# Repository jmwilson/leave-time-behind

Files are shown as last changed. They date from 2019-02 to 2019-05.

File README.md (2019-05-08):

## Introduction

*Leave Time Behind* is experimental timepiece that invites the viewer to have a looser hold on time. The project takes the form of a desk clock that displays time as a continuous glowing bar that advances gradually over the course of the day. Compared to a traditional clock that allows us to obsess over hours and minutes, *Leave Time Behind* only permits the viewer to mark time and intervals approximately in relation to the natural cycle of the day.

The project was inspired by my experiences at Camp Grounded, a tech-free summer camp for adults. One of the rules of camp was to "leave time behind" -- for a weekend, we put away watches, phones, and alarms, and measured time only by the sun and stars.

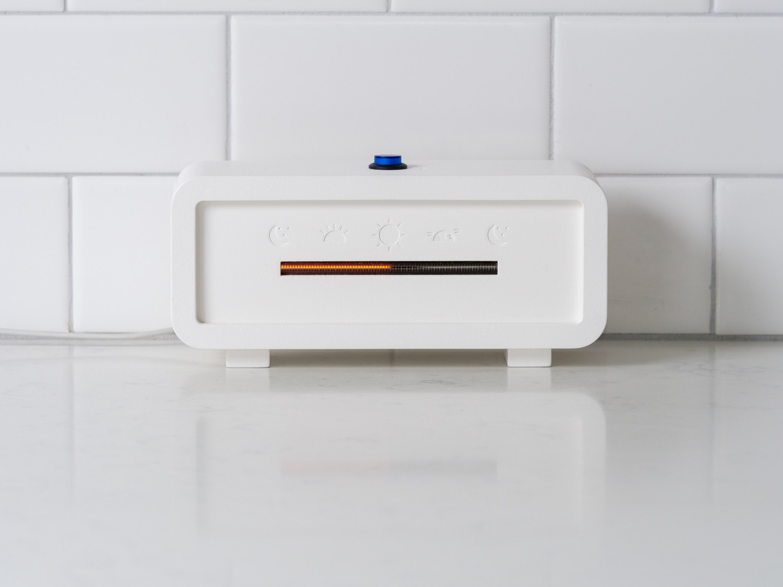
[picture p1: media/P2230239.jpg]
Picture of clock


## Details

The desk clock is primarily an electronic device. A custom printed circuit board (PCB) houses the main components of the electronics design: a switched-mode DC-DC power supply, a microcontroller with Bluetooth low-energy connectivity that keeps time, and a driver circuit that converts the digital time output from the microcontroller to an analog control signal.

The time is displayed on an IN-13 [Nixie tube](https://en.wikipedia.org/wiki/Nixie_tube). By varying the current through the tube, the length of the glowing segment can be controlled. Nixie tubes were chosen for their warm glow and analog aethestic.

When I thought of the design of the clock, I wanted it to have the minimum interface possible. In keeping with the aim to de-emphasize attention to hours and minutes, there are no discrete controls to set the exact time. To set the time, a single button on the top of the enclosure activates the Bluetooth function. When paired with a smartphone, the clock reads the time from the device.

I wanted the clock to work without the need for special wall adapters or connectors, and considered the USB phone charger to be the ideal power adapter that everyone has that could be reused or repurposed. Since USB provides power at 5 VDC, whereas Nixie tubes have a typical firing voltage of 150 - 170 VDC, this required a custom switched-mode DC-DC power supply. The power supply operates in [boost topology](https://en.wikipedia.org/wiki/Boost_converter) in discontinuous current mode (DCM) at a switching frequency of 100 kHz.

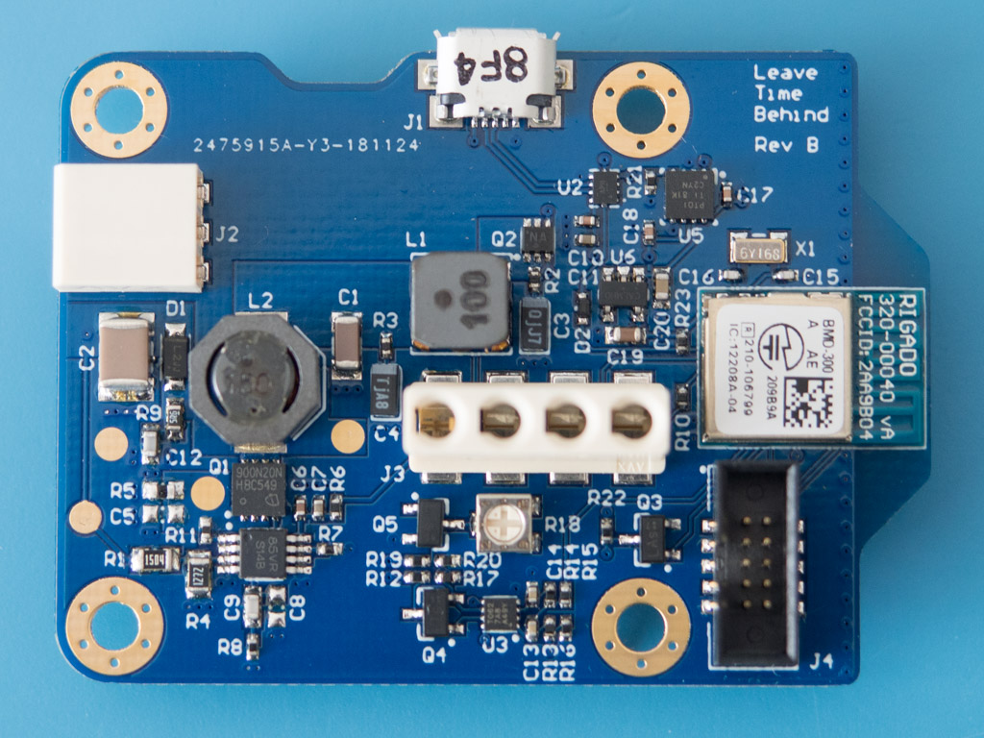
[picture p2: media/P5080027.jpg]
Closeup of PCB

*Close-up of the PCB*

## Future work

The clock enclosure was 3D printed from nylon plastic for expediency, but my original concept called for a wood enclosure that would complement the warm, retro aesthetic of the Nixie tube.

An alternative to bootstrapping the time from a smartphone is to use GPS to determine the time relative to local sunrise and sunset. Such a clock could set its own time without any interaction. Since it would display time relative to sunrise and sunset, it need not be concerned with the vagaries of time zones or daylight saving time.

## Understanding this repository

`CAD files`: details of the physical enclosure design including STL files that can be 3D-printed. The enclosure was designed using [Autodesk Fusion 360](https://www.autodesk.com/products/fusion-360/overview).

`PCB`: design files for the printed circuit board, including schematic sheets and layouts. The circuit board was designed using [Altium Designer](https://www.altium.com/altium-designer/). The latest Gerber files for manufacturing are in `Gerbers.zip`. A PDF of the compiled schematic sheets is in `Schematic.pdf`.

`Design scripts` and `spice`: contains various simulation and scripts primarily for the design and tuning of the switching power supply. The simulations use [LTspice](https://www.linear.com/ltspice), a free-to-use SPICE implementation.

`Scope captures`: oscilloscope screen captures documenting the performance and characteristics of the power supply. Most of the captures are annotated with the subject and conditions of the test.

`firmware`: C code for the [nRF5 microcontroller](https://www.nordicsemi.com/).

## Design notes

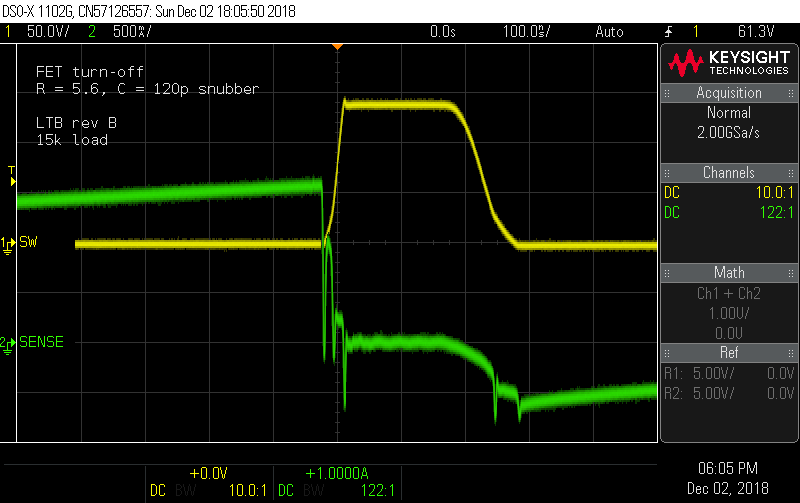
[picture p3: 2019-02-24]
Scope captures/Rev B/scope_15.png

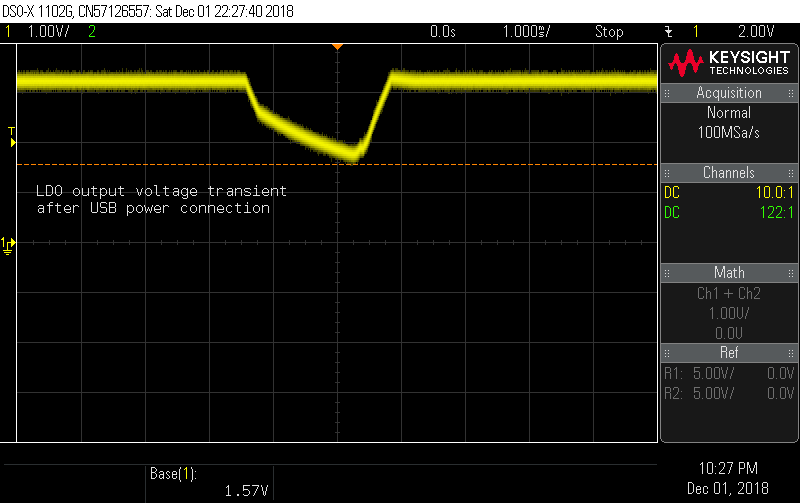
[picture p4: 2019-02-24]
Scope captures/Rev B/scope_12.png

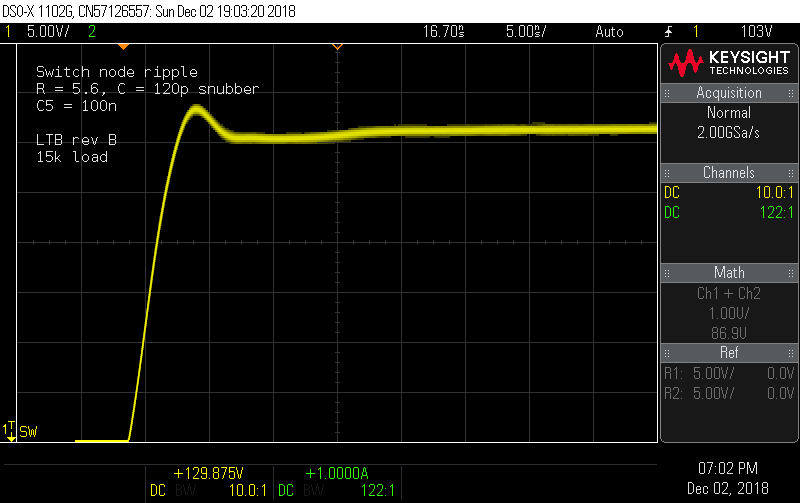
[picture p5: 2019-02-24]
Scope captures/Rev B/scope_22.png

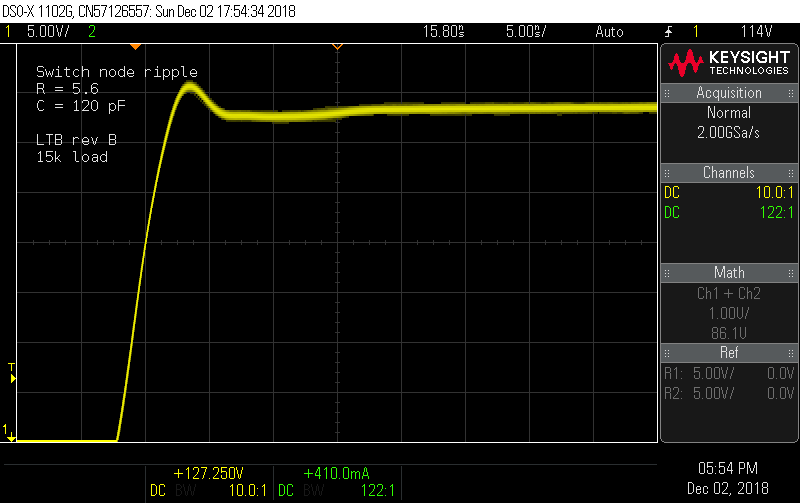
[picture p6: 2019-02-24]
Scope captures/Rev B/scope_14.png

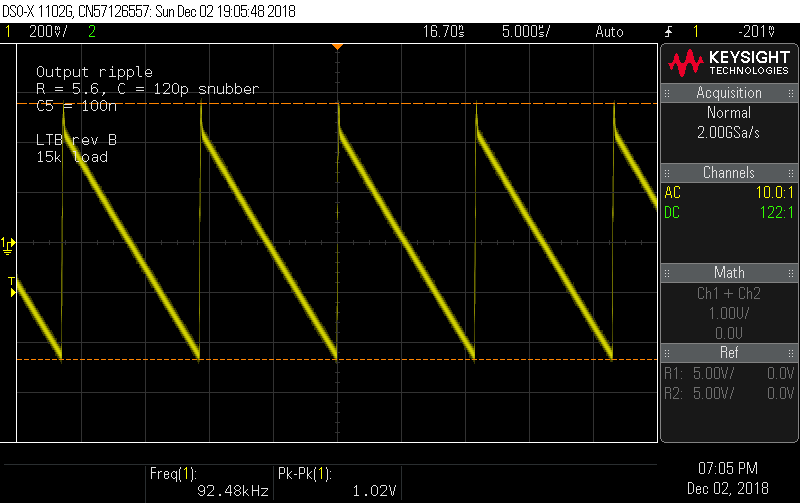
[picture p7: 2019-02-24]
Scope captures/Rev B/scope_23.png

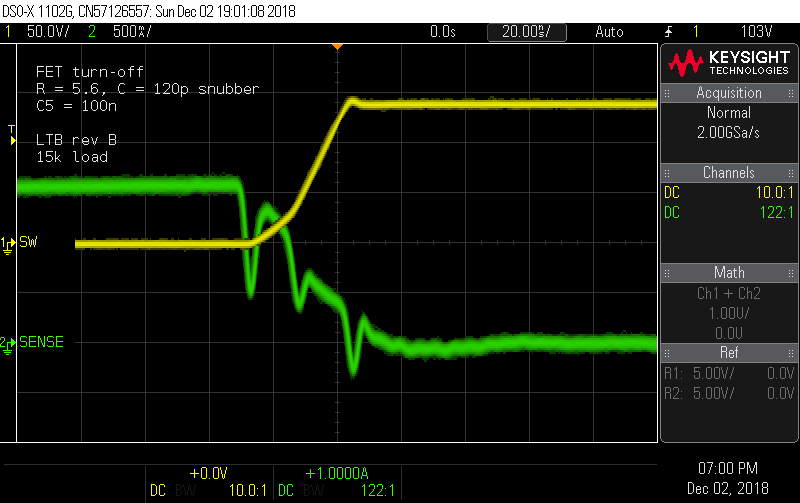
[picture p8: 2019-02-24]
Scope captures/Rev B/scope_21.png

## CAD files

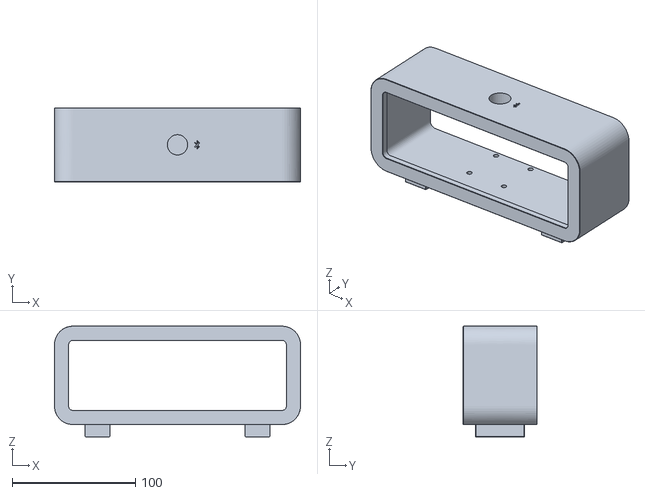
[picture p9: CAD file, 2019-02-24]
CAD files/Frame.stl
200.0 x 60.0 x 90.0

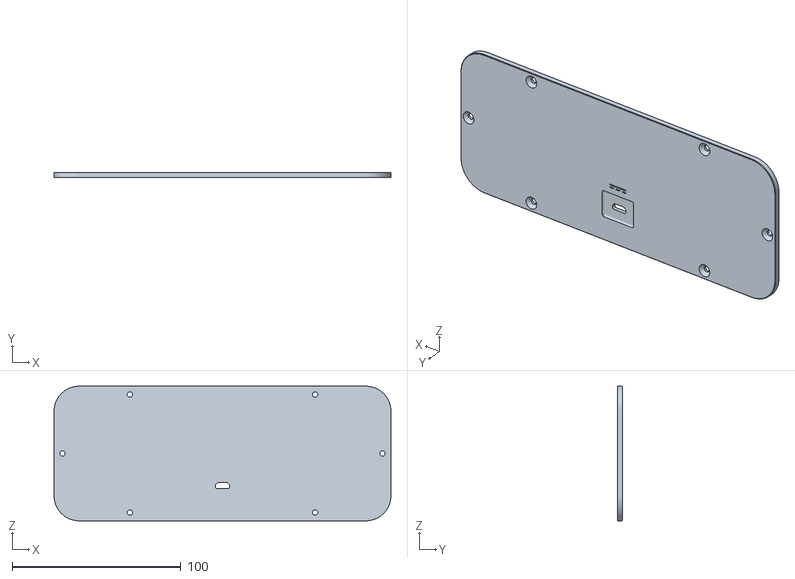
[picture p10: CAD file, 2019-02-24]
CAD files/Back panel.stl
200.0 x 3.00 x 80.0

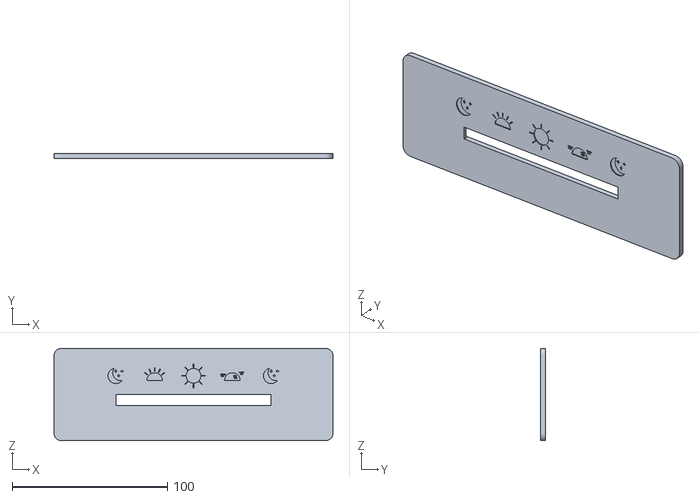
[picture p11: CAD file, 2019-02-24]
CAD files/Front panel.stl
179.5 x 3.00 x 59.5

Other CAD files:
CAD files/Enclosure.f3z

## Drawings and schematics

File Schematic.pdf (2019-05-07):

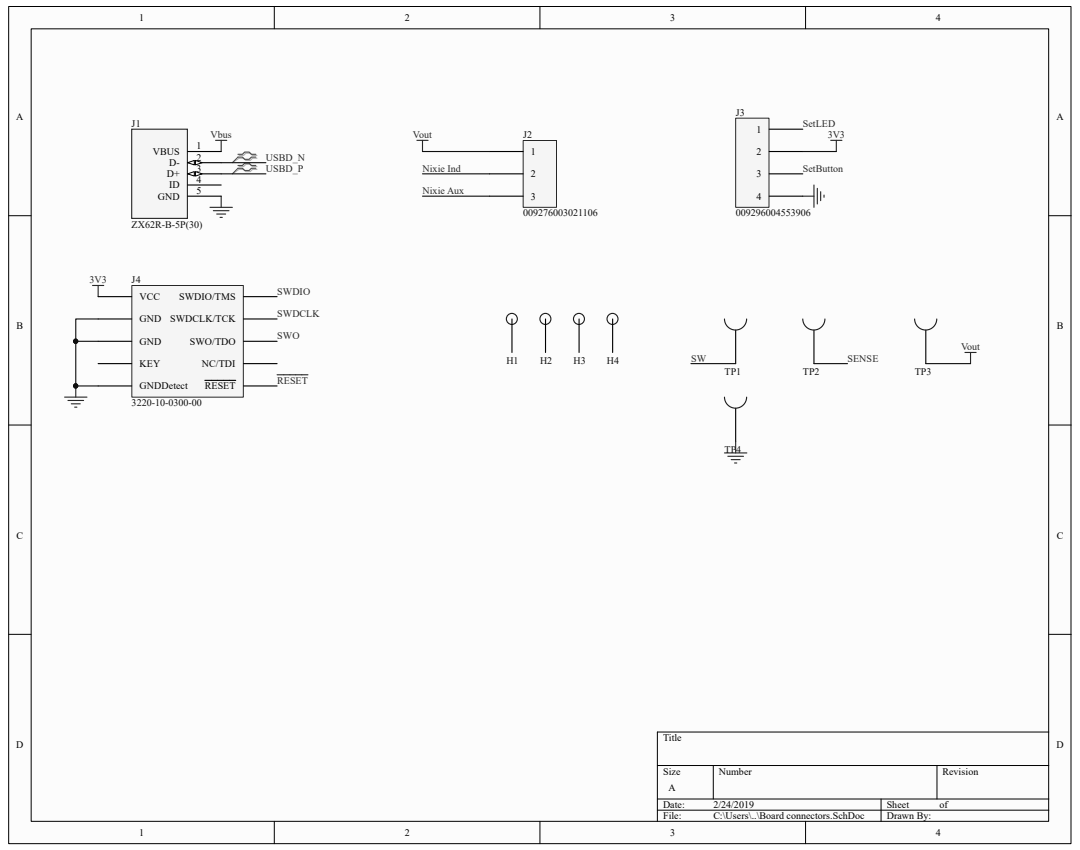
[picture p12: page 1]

IN1+ 4 8

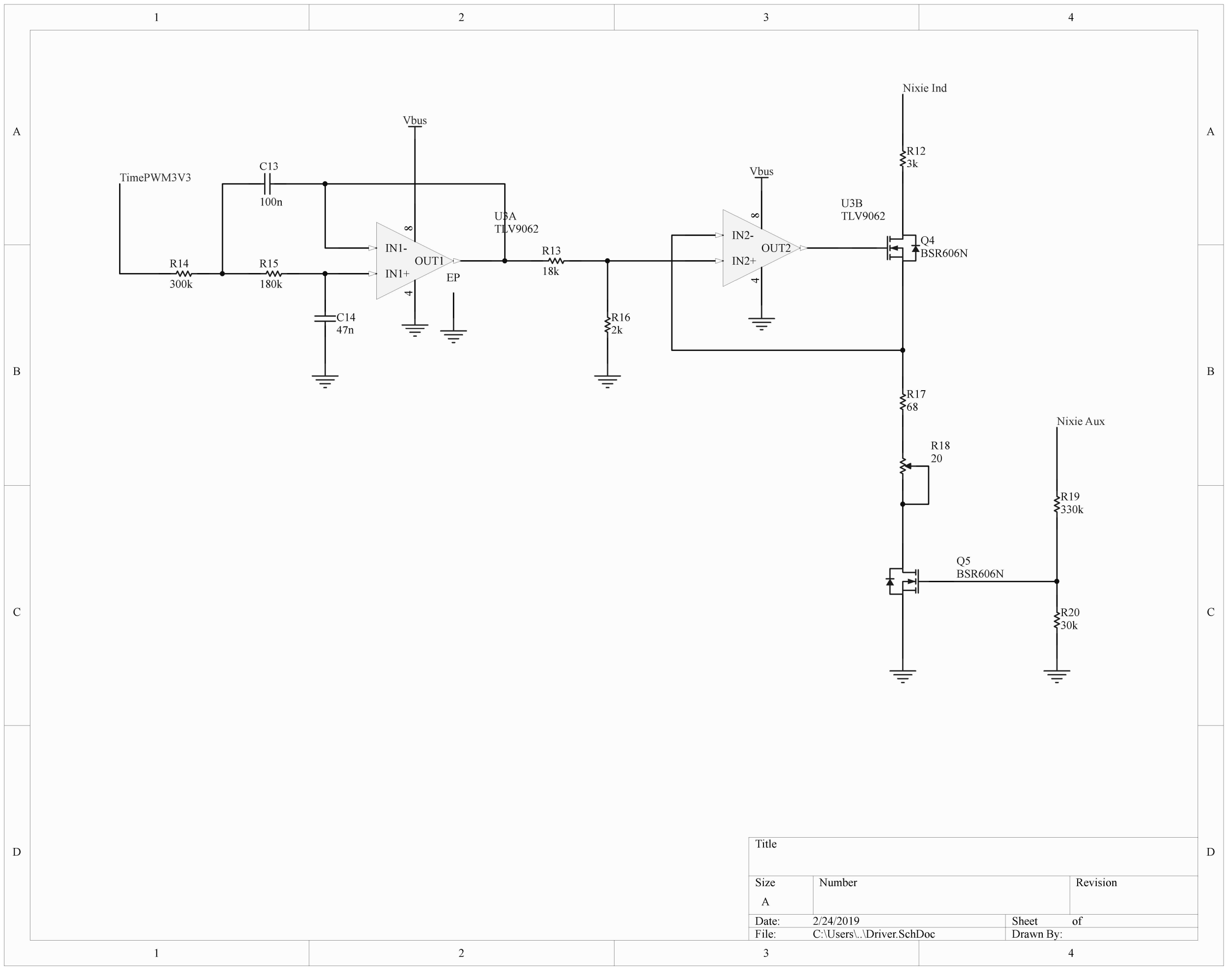
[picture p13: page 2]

D D

C C

B B

A A

Title

Size | Number | Revision
File: | C:\Users\..\Driver.SchDoc | Drawn By:

EP

OUT1

IN1-

U3A
TLV9062 | 4 8 OUT2
| IN2-
| IN2+

U3B
TLV9062

Vbus

Vbus TimePWM3V3

R14
300k

R15
180k

C13

100n

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
330k

R20
30k

R18
20

Q4
BSR606N

Q5
BSR606N

Nixie Ind

Nixie Aux

# U4 SetButton

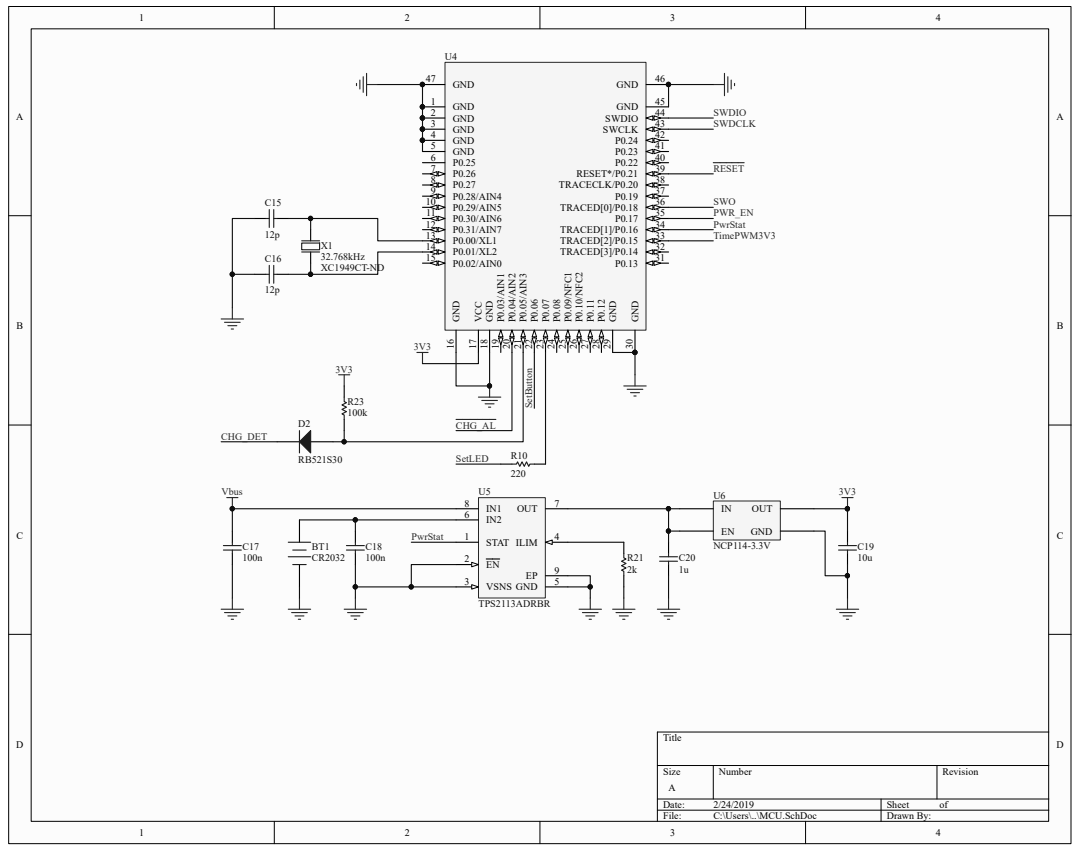
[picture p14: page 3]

4 5, 6, 7, 8, 9 1, 2, 3

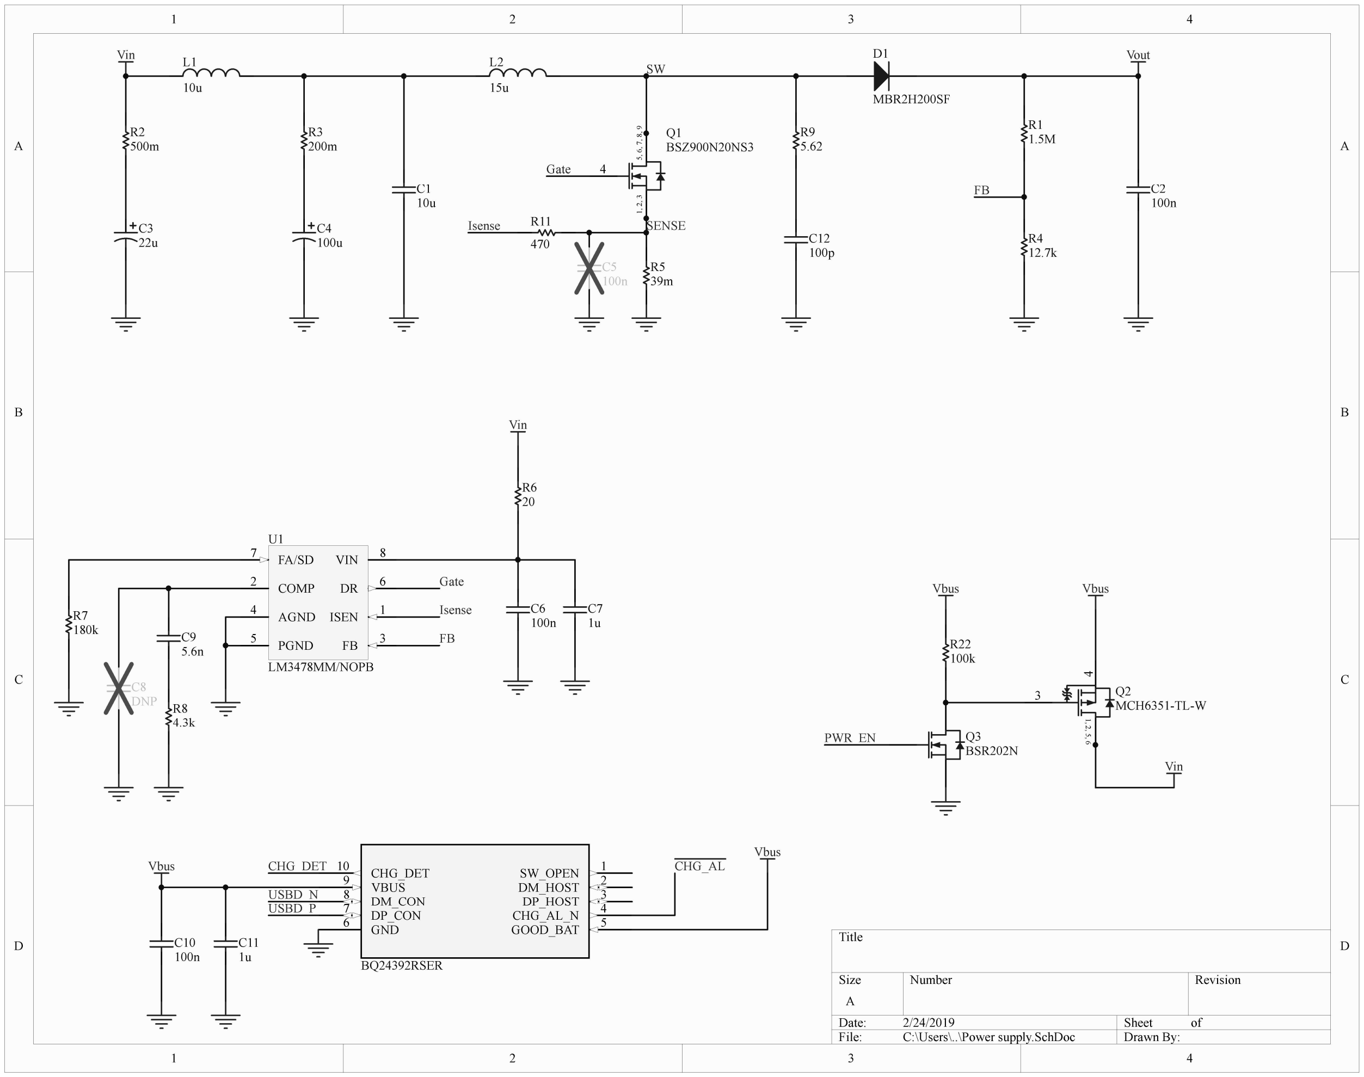
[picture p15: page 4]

D D

C C

B B

A A

Title

Size | Number | Revision
File: | C:\Users\..\Power supply.SchDoc | Drawn By:
VIN | 8
DR | 6

PGND 5

AGND 4

ISEN 1

FA/SD 7

COMP 2

FB 3

U1

LM3478MM/NOPB

SW_OPEN | 1
DM_HOST | 2
DP_HOST | 3
CHG_AL_N | 4
GOOD_BAT | 5 GND 6

DP_CON 7

DM_CON 8

VBUS 9

CHG_DET 10

BQ24392RSER

CHG_DET

Vbus

Isense

Isense

D1

MBR2H200SF

R1
1.5M

R4
12.7k

FB

FB

Vout

R6
20

Gate

Gate
C1
10u

C6
100n

USBD_N
USBD_P

Vbus

C10
100n

3 4 1, 2, 5, 6
Q2
MCH6351-TL-W

Vbus

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
100u

C8
DNP

R2
500m

R3
200m

C7
1u

C11
1u

PWR_EN

SW

SENSE

C5
100n

CHG_AL

Q1
BSZ900N20NS3

L2

15u

Q3
BSR202N

Vbus

R22
100k

C2
100n

R9
5.62

C12
100p

R7
180k | C9
| 5.6n

R8
4.3k

R5
39m

R11
470

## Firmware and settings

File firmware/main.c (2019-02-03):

/**
 * Copyright (c) 2018-2019 James Wilson
 * All rights reserved.
 *
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
 * You should have received a copy of the GNU General Public License
 * along with this program.  If not, see <https://www.gnu.org/licenses/>.
 */

#include <stdint.h>
#include <string.h>
#include "nrf.h"
#include "app_error.h"
#include "app_scheduler.h"
#include "app_timer.h"
#include "ble.h"
#include "ble_cts_c.h"
#include "ble_db_discovery.h"
#include "ble_hci.h"
#include "ble_srv_common.h"
#include "ble_advdata.h"
#include "ble_advertising.h"
#include "ble_conn_params.h"
#include "bsp.h"
#include "peer_manager.h"
#include "nordic_common.h"
#include "nrf_sdh.h"
#include "nrf_sdh_soc.h"
#include "nrf_sdh_ble.h"
#include "nrfx_gpiote.h"
#include "nrfx_pwm.h"
#include "ble_conn_state.h"
#include "nrf_ble_gatt.h"
#include "nrf_ble_qwr.h"

#include "nrf_log.h"
#include "nrf_log_ctrl.h"
#include "nrf_log_default_backends.h"

#include "nrf_calendar.h"


#define DEVICE_NAME                     "Leave Time Behind"

#define APP_BLE_OBSERVER_PRIO           3
#define APP_BLE_CONN_CFG_TAG            1  // A tag identifying the SoftDevice BLE configuration

#define APP_ADV_FAST_INTERVAL           0x0028  // Fast advertising interval (in units of 0.625 ms) = 25 ms
#define APP_ADV_SLOW_INTERVAL           0x0C80  // Slow advertising interval (in units of 0.625 ms) = 2s

#define APP_ADV_FAST_DURATION           3000   // Fast Advertising duration in units of 10 milliseconds
#define APP_ADV_SLOW_DURATION           18000  // Slow advertising duration in units 10 milliseconds


#define MIN_CONN_INTERVAL               MSEC_TO_UNITS(500, UNIT_1_25_MS)   // Minimum acceptable connection interval (0.5 seconds)
#define MAX_CONN_INTERVAL               MSEC_TO_UNITS(1000, UNIT_1_25_MS)  // Maximum acceptable connection interval (1 second)
#define SLAVE_LATENCY                   0
#define CONN_SUP_TIMEOUT                MSEC_TO_UNITS(4000, UNIT_10_MS)  // Connection supervisory time-out (4 seconds)
#define FIRST_CONN_PARAMS_UPDATE_DELAY  APP_TIMER_TICKS(5000)  // Time from connect to first sd_ble_gap_conn_param_update
#define NEXT_CONN_PARAMS_UPDATE_DELAY   APP_TIMER_TICKS(30000)  // Time between subsequent calls to sd_ble_gap_conn_param_update
#define MAX_CONN_PARAMS_UPDATE_COUNT    3  // Number of attempts before giving up the connection parameter negotiation

// Parameters for Just Works security and no IO capabiltiies
#define SEC_PARAM_BOND                  0
#define SEC_PARAM_MITM                  0
#define SEC_PARAM_LESC                  0
#define SEC_PARAM_KEYPRESS              0
#define SEC_PARAM_IO_CAPABILITIES       BLE_GAP_IO_CAPS_NONE
#define SEC_PARAM_OOB                   0
#define SEC_PARAM_MIN_KEY_SIZE          7
#define SEC_PARAM_MAX_KEY_SIZE          16

#define SCHED_MAX_EVENT_DATA_SIZE       APP_TIMER_SCHED_EVENT_DATA_SIZE
#ifdef SVCALL_AS_NORMAL_FUNCTION
// Maximum number of events in the scheduler queue.
#define SCHED_QUEUE_SIZE                20
#else
#define SCHED_QUEUE_SIZE                10
#endif

#define DEAD_BEEF                       0xDEADBEEF


BLE_CTS_C_DEF(m_cts_c);  // Current Time service instance
NRF_BLE_GATT_DEF(m_gatt);  // GATT module instance
NRF_BLE_QWR_DEF(m_qwr);  // Context for the Queued Write module
BLE_ADVERTISING_DEF(m_advertising);  // Advertising module instance
BLE_DB_DISCOVERY_DEF(m_ble_db_discovery);  // DB discovery module instance

static bool         m_pwr_en = false;  // Power state, true = on USB power, false = on backup battery
static uint16_t     m_cur_conn_handle = BLE_CONN_HANDLE_INVALID;  // Handle of the current connection

#define PWM_INVERT_OUTPUT ((uint16_t)0x8000)
#define PWM_TOP_VALUE 1600  // At 16 MHz, this sets a PWM frequency of 10 kHz
#define PWM_BASE_VALUE 160  // Beginning of the working section is about 10% of the max current
static nrfx_pwm_t pwm_inst = NRFX_PWM_INSTANCE(0);
static nrf_pwm_values_common_t pwm_values[] = {PWM_INVERT_OUTPUT | 0};

static ble_uuid_t m_adv_uuids[] = {{BLE_UUID_CURRENT_TIME_SERVICE, BLE_UUID_TYPE_BLE}};

APP_TIMER_DEF(ble_disconnect_timer);


/**
 * Callback function for asserts in the SoftDevice.
 *
 * @param[in] line_num  Line number of the failing ASSERT call.
 * @param[in] file_name File name of the failing ASSERT call.
 */
void assert_nrf_callback(uint16_t line_num, const uint8_t * p_file_name)
{
    app_error_handler(DEAD_BEEF, line_num, p_file_name);
}


static void advertising_start(void)
{
    ret_code_t ret;

    ret = ble_advertising_start(&m_advertising, BLE_ADV_MODE_FAST);
    if (ret != NRF_ERROR_INVALID_STATE) {
        APP_ERROR_CHECK(ret);
    }
}


static void pm_evt_handler(pm_evt_t const * p_evt)
{
    ret_code_t err_code;

    switch (p_evt->evt_id) {
        case PM_EVT_CONN_SEC_SUCCEEDED:
            NRF_LOG_INFO("Connection secured: role: %d, conn_handle: 0x%x, procedure: %d.",
                         ble_conn_state_role(p_evt->conn_handle),
                         p_evt->conn_handle,
                         p_evt->params.conn_sec_succeeded.procedure);

            // Discover peer's services.
            err_code  = ble_db_discovery_start(&m_ble_db_discovery, p_evt->conn_handle);
            APP_ERROR_CHECK(err_code);
            break;

        case PM_EVT_CONN_SEC_FAILED:
            break;

        case PM_EVT_ERROR_UNEXPECTED:
            APP_ERROR_CHECK(p_evt->params.error_unexpected.error);
            break;

        default:
            break;
    }
}


/**
 * Handler for Current Time Service errors.
 *
 * @param[in]  nrf_error  Error code containing information about what went wrong.
 */
static void current_time_error_handler(uint32_t nrf_error)
{
    APP_ERROR_HANDLER(nrf_error);
}


static void ble_disconnect_timer_handler(void *p_context)
{
    ble_cts_c_t *cts = (ble_cts_c_t *)p_context;
    (void)sd_ble_gap_disconnect(cts->conn_handle,
                                BLE_HCI_REMOTE_USER_TERMINATED_CONNECTION);
}


static void timers_init(void)
{
    ret_code_t err_code;

    err_code = app_timer_init();
    APP_ERROR_CHECK(err_code);

    err_code = app_timer_create(&ble_disconnect_timer,
        APP_TIMER_MODE_SINGLE_SHOT, ble_disconnect_timer_handler);
    APP_ERROR_CHECK(err_code);
}


/**
 * Handler for Current Time Service client events.
 *
 * @param[in] p_evt Event received from the Current Time Service client.
 */
static void on_cts_c_evt(ble_cts_c_t * p_cts, ble_cts_c_evt_t * p_evt)
{
    ret_code_t err_code;

    switch (p_evt->evt_type) {
        case BLE_CTS_C_EVT_DISCOVERY_COMPLETE:
            NRF_LOG_INFO("Current Time Service discovered on server.");
            err_code = ble_cts_c_handles_assign(p_cts,
                                                p_evt->conn_handle,
                                                &p_evt->params.char_handles);
            APP_ERROR_CHECK(err_code);
            err_code = ble_cts_c_current_time_read(p_cts);
            APP_ERROR_CHECK(err_code);
            break;

        case BLE_CTS_C_EVT_DISCOVERY_FAILED:
            NRF_LOG_INFO("Current Time Service not found on server. ");
            if (p_evt->conn_handle != BLE_CONN_HANDLE_INVALID)
            {
                err_code = sd_ble_gap_disconnect(p_evt->conn_handle,
                                                 BLE_HCI_REMOTE_USER_TERMINATED_CONNECTION);
                APP_ERROR_CHECK(err_code);
            }
            break;

        case BLE_CTS_C_EVT_DISCONN_COMPLETE:
            NRF_LOG_INFO("Disconnect Complete.");
            break;

        case BLE_CTS_C_EVT_CURRENT_TIME:
            NRF_LOG_INFO("Current Time received.");
            err_code = bsp_indication_set(BSP_INDICATE_RCV_OK);
            APP_ERROR_CHECK(err_code);
            nrf_cal_set_time(
                p_evt->params.current_time.exact_time_256.day_date_time.date_time.year,
                p_evt->params.current_time.exact_time_256.day_date_time.date_time.month,
                p_evt->params.current_time.exact_time_256.day_date_time.date_time.day,
                p_evt->params.current_time.exact_time_256.day_date_time.date_time.hours,
                p_evt->params.current_time.exact_time_256.day_date_time.date_time.minutes,
                p_evt->params.current_time.exact_time_256.day_date_time.date_time.seconds +
                    (p_evt->params.current_time.exact_time_256.fractions256 >= 128 ? 1 : 0)
            );
            (void)app_timer_start(ble_disconnect_timer, APP_TIMER_TICKS(5000), (void *)p_cts);
            break;

        case BLE_CTS_C_EVT_INVALID_TIME:
            NRF_LOG_INFO("Invalid Time received.");
            err_code = bsp_indication_set(BSP_INDICATE_RCV_ERROR);
            APP_ERROR_CHECK(err_code);
            break;

        default:
            break;
    }
}


static void gap_params_init(void)
{
    ret_code_t              err_code;
    ble_gap_conn_params_t   gap_conn_params;
    ble_gap_conn_sec_mode_t sec_mode;

    BLE_GAP_CONN_SEC_MODE_SET_OPEN(&sec_mode);

    err_code = sd_ble_gap_device_name_set(&sec_mode,
                                          (const uint8_t *)DEVICE_NAME,
                                          strlen(DEVICE_NAME));
    APP_ERROR_CHECK(err_code);
    err_code = sd_ble_gap_appearance_set(BLE_APPEARANCE_GENERIC_CLOCK);
    APP_ERROR_CHECK(err_code);
    memset(&gap_conn_params, 0, sizeof(gap_conn_params));

    gap_conn_params.min_conn_interval = MIN_CONN_INTERVAL;
    gap_conn_params.max_conn_interval = MAX_CONN_INTERVAL;
    gap_conn_params.slave_latency     = SLAVE_LATENCY;
    gap_conn_params.conn_sup_timeout  = CONN_SUP_TIMEOUT;

    err_code = sd_ble_gap_ppcp_set(&gap_conn_params);
    APP_ERROR_CHECK(err_code);
}


static void gatt_init(void)
{
    ret_code_t err_code = nrf_ble_gatt_init(&m_gatt, NULL);
    APP_ERROR_CHECK(err_code);
}

/**
 * Handler for Queued Write Module errors.
 *
 * @param[in]   nrf_error   Error code containing information about what went wrong.
 */
static void nrf_qwr_error_handler(uint32_t nrf_error)
{
    APP_ERROR_HANDLER(nrf_error);
}


static void services_init(void)
{
    ret_code_t         err_code;
    ble_cts_c_init_t   cts_init = {0};
    nrf_ble_qwr_init_t qwr_init = {0};

    // Initialize Queued Write Module.
    qwr_init.error_handler = nrf_qwr_error_handler;
    err_code = nrf_ble_qwr_init(&m_qwr, &qwr_init);
    APP_ERROR_CHECK(err_code);

    // Initialize CTS.
    cts_init.evt_handler   = on_cts_c_evt;
    cts_init.error_handler = current_time_error_handler;
    err_code = ble_cts_c_init(&m_cts_c, &cts_init);
    APP_ERROR_CHECK(err_code);
}


/**
 * Handler for Connection Parameters module errors.
 *
 * @param[in]   nrf_error   Error code containing information about what went wrong.
 */
static void conn_params_error_handler(uint32_t nrf_error)
{
    APP_ERROR_HANDLER(nrf_error);
}


static void conn_params_init(void)
{
    ret_code_t             err_code;
    ble_conn_params_init_t cp_init;

    memset(&cp_init, 0, sizeof(cp_init));

    cp_init.p_conn_params                  = NULL;
    cp_init.first_conn_params_update_delay = FIRST_CONN_PARAMS_UPDATE_DELAY;
    cp_init.next_conn_params_update_delay  = NEXT_CONN_PARAMS_UPDATE_DELAY;
    cp_init.max_conn_params_update_count   = MAX_CONN_PARAMS_UPDATE_COUNT;
    cp_init.start_on_notify_cccd_handle    = BLE_GATT_HANDLE_INVALID;
    cp_init.disconnect_on_fail             = true;
    cp_init.error_handler                  = conn_params_error_handler;

    err_code = ble_conn_params_init(&cp_init);
    APP_ERROR_CHECK(err_code);
}


static void db_disc_handler(ble_db_discovery_evt_t * p_evt)
{
    ble_cts_c_on_db_disc_evt(&m_cts_c, p_evt);
}


static void on_adv_evt(ble_adv_evt_t ble_adv_evt)
{
    ret_code_t err_code;

    switch (ble_adv_evt) {
        case BLE_ADV_EVT_FAST:
            NRF_LOG_INFO("Fast advertising");
            err_code = bsp_indication_set(BSP_INDICATE_ADVERTISING);
            APP_ERROR_CHECK(err_code);
            break;

        case BLE_ADV_EVT_SLOW:
            NRF_LOG_INFO("Slow advertising");
            err_code = bsp_indication_set(BSP_INDICATE_ADVERTISING_SLOW);
            APP_ERROR_CHECK(err_code);
            break;

        case BLE_ADV_EVT_IDLE:
            NRF_LOG_INFO("Stopping advertising");
            err_code = bsp_indication_set(BSP_INDICATE_IDLE);
            APP_ERROR_CHECK(err_code);
            break;

        default:
            break;
    }
}


static void ble_evt_handler(ble_evt_t const * p_ble_evt, void * p_context)
{
    ret_code_t err_code;
    pm_conn_sec_status_t status;

    switch (p_ble_evt->header.evt_id) {
        case BLE_GAP_EVT_CONNECTED:
            NRF_LOG_INFO("Connected.");
            m_cur_conn_handle = p_ble_evt->evt.gap_evt.conn_handle;
            err_code = nrf_ble_qwr_conn_handle_assign(&m_qwr, m_cur_conn_handle);
            APP_ERROR_CHECK(err_code);
            err_code = pm_conn_sec_status_get(m_cur_conn_handle, &status);
            APP_ERROR_CHECK(err_code);
            if (!status.encrypted) {
                err_code = pm_conn_secure(m_cur_conn_handle, false);
                APP_ERROR_CHECK(err_code);
            }
            err_code = bsp_indication_set(BSP_INDICATE_CONNECTED);
            APP_ERROR_CHECK(err_code);
            break;

        case BLE_GAP_EVT_DISCONNECTED:
            NRF_LOG_INFO("Disconnected.");
            m_cur_conn_handle = BLE_CONN_HANDLE_INVALID;
            if (p_ble_evt->evt.gap_evt.conn_handle == m_cts_c.conn_handle) {
                m_cts_c.conn_handle = BLE_CONN_HANDLE_INVALID;
            }
            err_code = bsp_indication_set(BSP_INDICATE_IDLE);
            APP_ERROR_CHECK(err_code);
            break;

        case BLE_GAP_EVT_PHY_UPDATE_REQUEST:
            NRF_LOG_DEBUG("PHY update request.");
            ble_gap_phys_t const phys =
            {
                .rx_phys = BLE_GAP_PHY_AUTO,
                .tx_phys = BLE_GAP_PHY_AUTO,
            };
            err_code = sd_ble_gap_phy_update(p_ble_evt->evt.gap_evt.conn_handle, &phys);
            APP_ERROR_CHECK(err_code);
            break;

        case BLE_GATTC_EVT_TIMEOUT:
            // Disconnect on GATT Client timeout event.
            NRF_LOG_DEBUG("GATT Client Timeout.");
            err_code = sd_ble_gap_disconnect(p_ble_evt->evt.gattc_evt.conn_handle,
                                             BLE_HCI_REMOTE_USER_TERMINATED_CONNECTION);
            APP_ERROR_CHECK(err_code);
            break;

        case BLE_GATTS_EVT_TIMEOUT:
            // Disconnect on GATT Server timeout event.
            NRF_LOG_DEBUG("GATT Server Timeout.");
            err_code = sd_ble_gap_disconnect(p_ble_evt->evt.gatts_evt.conn_handle,
                                             BLE_HCI_REMOTE_USER_TERMINATED_CONNECTION);
            APP_ERROR_CHECK(err_code);
            break;

        default:
            break;
    }
}
NRF_SDH_BLE_OBSERVER(m_ble_observer, APP_BLE_OBSERVER_PRIO, ble_evt_handler, NULL);


void bsp_event_handler(bsp_event_t event)
{
    switch (event) {
        case BSP_EVENT_KEY_0:
            NRF_LOG_INFO("Current time: %s", nrf_log_push(nrf_cal_get_time_string()));
            break;

        case BSP_EVENT_ADVERTISING_START:
            if (m_cur_conn_handle == BLE_CONN_HANDLE_INVALID && m_pwr_en) {
                advertising_start();
            }
            break;

        default:
            break;
    }
}


static void ble_stack_init(void)
{
    ret_code_t err_code;

    err_code = nrf_sdh_enable_request();
    APP_ERROR_CHECK(err_code);

    // Configure the BLE stack using the default settings.
    // Fetch the start address of the application RAM.
    uint32_t ram_start = 0;
    err_code = nrf_sdh_ble_default_cfg_set(APP_BLE_CONN_CFG_TAG, &ram_start);
    APP_ERROR_CHECK(err_code);

    // Enable BLE stack.
    err_code = nrf_sdh_ble_enable(&ram_start);
    APP_ERROR_CHECK(err_code);
}


static void scheduler_init(void)
{
    APP_SCHED_INIT(SCHED_MAX_EVENT_DATA_SIZE, SCHED_QUEUE_SIZE);
}


static void buttons_leds_init(void)
{
    ret_code_t err_code;

    err_code = bsp_init(BSP_INIT_LEDS | BSP_INIT_BUTTONS, bsp_event_handler);
    APP_ERROR_CHECK(err_code);

    err_code = bsp_event_to_button_action_assign(
        0, BSP_BUTTON_ACTION_LONG_PUSH, BSP_EVENT_ADVERTISING_START);
    APP_ERROR_CHECK(err_code);
}


static void peer_manager_init(void)
{
    ble_gap_sec_params_t sec_param;
    ret_code_t           err_code;

    err_code = pm_init();
    APP_ERROR_CHECK(err_code);

    memset(&sec_param, 0, sizeof(ble_gap_sec_params_t));

    // Security parameters for Just Works pairing without bonding
    sec_param.bond           = SEC_PARAM_BOND;
    sec_param.mitm           = SEC_PARAM_MITM;
    sec_param.lesc           = SEC_PARAM_LESC;
    sec_param.keypress       = SEC_PARAM_KEYPRESS;
    sec_param.io_caps        = SEC_PARAM_IO_CAPABILITIES;
    sec_param.oob            = SEC_PARAM_OOB;
    sec_param.min_key_size   = SEC_PARAM_MIN_KEY_SIZE;
    sec_param.max_key_size   = SEC_PARAM_MAX_KEY_SIZE;
    sec_param.kdist_own.enc  = 0;
    sec_param.kdist_own.id   = 0;
    sec_param.kdist_peer.enc = 0;
    sec_param.kdist_peer.id  = 0;

    err_code = pm_sec_params_set(&sec_param);
    APP_ERROR_CHECK(err_code);

    err_code = pm_register(pm_evt_handler);
    APP_ERROR_CHECK(err_code);
}


static void advertising_init()
{
    ret_code_t             err_code;
    ble_advertising_init_t init;

    memset(&init, 0, sizeof(init));

    init.advdata.name_type                = BLE_ADVDATA_FULL_NAME;
    init.advdata.include_appearance       = true;
    init.advdata.flags                    = BLE_GAP_ADV_FLAGS_LE_ONLY_LIMITED_DISC_MODE;
    init.advdata.uuids_solicited.uuid_cnt = sizeof(m_adv_uuids) / sizeof(m_adv_uuids[0]);
    init.advdata.uuids_solicited.p_uuids  = m_adv_uuids;

    init.config.ble_adv_on_disconnect_disabled = true;
    init.config.ble_adv_fast_enabled      = true;
    init.config.ble_adv_fast_interval     = APP_ADV_FAST_INTERVAL;
    init.config.ble_adv_fast_timeout      = APP_ADV_FAST_DURATION;
    init.config.ble_adv_slow_enabled      = true;
    init.config.ble_adv_slow_interval     = APP_ADV_SLOW_INTERVAL;
    init.config.ble_adv_slow_timeout      = APP_ADV_SLOW_DURATION;
    init.evt_handler = on_adv_evt;

    err_code = ble_advertising_init(&m_advertising, &init);
    APP_ERROR_CHECK(err_code);

    ble_advertising_conn_cfg_tag_set(&m_advertising, APP_BLE_CONN_CFG_TAG);
}


static void db_discovery_init(void)
{
    ret_code_t err_code = ble_db_discovery_init(db_disc_handler);
    APP_ERROR_CHECK(err_code);
}


static void log_init(void)
{
    ret_code_t err_code = NRF_LOG_INIT(NULL);
    APP_ERROR_CHECK(err_code);

    NRF_LOG_DEFAULT_BACKENDS_INIT();
}


static void idle_state_handle(void)
{
    ret_code_t err_code;

    app_sched_execute();

    if (NRF_LOG_PROCESS() == false) {
        err_code = sd_app_evt_wait();
        APP_ERROR_CHECK(err_code);
    }
}

static void pwm_handler(nrfx_pwm_evt_type_t event_type)
{
    if (event_type == NRFX_PWM_EVT_FINISHED) {
        struct tm *current_time = nrf_cal_get_time();
        // tm_hour / 24 * (PWM_TOP_VALUE - PWM_BASE_VALUE) = tm_hour * 60
        // tm_min / (24 * 60) * (PWM_TOP_VALUE - PWM_BASE_VALUE) = tm_min
        // Set high bit to invert PWM:
        // https://devzone.nordicsemi.com/f/nordic-q-a/28263/invert-pwm-behaviour
        pwm_values[0] = PWM_INVERT_OUTPUT |
                        (PWM_BASE_VALUE + current_time->tm_hour * 60
                         + current_time->tm_min);
    }
}


static void pwm_start(void)
{
    nrf_pwm_sequence_t const seq = {
        .values.p_common = pwm_values,
        .length = NRF_PWM_VALUES_LENGTH(pwm_values),
        .repeats = 0,
        .end_delay = 0
    };

    (void)nrfx_pwm_simple_playback(
        &pwm_inst, &seq, 10000, NRFX_PWM_FLAG_LOOP);
}


static void pwm_init(void)
{
    nrfx_err_t err_code;
    nrfx_pwm_config_t config = {
        .output_pins = {
            TIME_PWM,
            NRFX_PWM_PIN_NOT_USED,
            NRFX_PWM_PIN_NOT_USED,
            NRFX_PWM_PIN_NOT_USED
        },
        .irq_priority = APP_IRQ_PRIORITY_LOWEST,
        .base_clock = NRF_PWM_CLK_16MHz,
        .count_mode = NRF_PWM_MODE_UP,
        .top_value = PWM_TOP_VALUE,
        .load_mode = NRF_PWM_LOAD_COMMON,
        .step_mode = NRF_PWM_STEP_AUTO
    };

    err_code = nrfx_pwm_init(&pwm_inst, &config, pwm_handler);
    APP_ERROR_CHECK(err_code);
}


/**
 * Set the power enable state based on signals from board power management
 * devices
 *
 * CHG_AL_N = BQ24392 active low output that charging is allowed
 * CHG_DET  = BQ24392 output that a battery charger/power adapter is detected
 * PWR_STAT = TPS2113 output that USB power source is active
 *
 * Returns true/false: power supply enabled/disabled
 */
static uint32_t set_power_enable_state(void)
{
    uint32_t chg_al_n = nrf_gpio_pin_read(CHG_AL_N);
    uint32_t chg_det = nrf_gpio_pin_read(CHG_DET);
    uint32_t pwr_stat = nrf_gpio_pin_read(PWR_STAT);
    m_pwr_en = !chg_al_n && chg_det && !pwr_stat;

    NRF_LOG_INFO(
        "Power state change: CHG_AL_N = %d, CHG_DET = %d, "
        "PWR_STAT = %d, PWR_EN = %d",
        chg_al_n,
        chg_det,
        pwr_stat,
        m_pwr_en
    );
    nrf_gpio_pin_write(PWR_EN, m_pwr_en);

    return m_pwr_en;
}
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
int main(void)
{
    log_init();
    timers_init();
    buttons_leds_init();
    scheduler_init();
    ble_stack_init();
    gap_params_init();
    gatt_init();
    db_discovery_init();
    advertising_init();
    peer_manager_init();
    services_init();
    conn_params_init();
    nrf_cal_init();
    pwm_init();
    gpio_init();

    for (;;) {
        idle_state_handle();
    }
}

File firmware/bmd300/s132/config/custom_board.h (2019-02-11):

#ifndef CUSTOM_BOARD_H
#define CUSTOM_BOARD_H

#ifdef __cplusplus
extern "C" {
#endif

#include "nrf_gpio.h"

#define LEDS_NUMBER    1

#define LED_START      7
#define LED_1          7
#define LED_STOP       7

#define LEDS_ACTIVE_STATE 0

#define LEDS_INV_MASK  LEDS_MASK

#define LEDS_LIST { LED_1 }

#define BSP_LED_0      LED_1

#define BUTTONS_NUMBER 1

#define BUTTON_START   6
#define BUTTON_1       6
#define BUTTON_STOP    6
#define BUTTON_PULL    NRF_GPIO_PIN_PULLUP

#define BUTTONS_ACTIVE_STATE 0

#define BUTTONS_LIST { BUTTON_1 }

#define BSP_BUTTON_0   BUTTON_1

#define CHG_AL_N       4
#define CHG_AL_N_PULL  NRF_GPIO_PIN_PULLUP
#define CHG_DET        5
#define CHG_DET_PULL   NRF_GPIO_PIN_NOPULL
#define TIME_PWM       15
#define PWR_STAT       16
#define PWR_STAT_PULL  NRF_GPIO_PIN_PULLUP
#define PWR_EN         17


#ifdef __cplusplus
}
#endif

#endif // CUSTOM_BOARD_H

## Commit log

2018-09-02 Working PWM
2018-09-02 Try to get VSCode to play with arm environment
2018-09-03 Add a disconnection timer after setting time
2018-09-15 Invert output polarity for PWM
    [main.c]
2018-10-30 Initial commit with IC + PCB antenna
    [Board connectors.SchDoc, Driver.SchDoc, Grounded clock.PrjPcb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]
2018-11-12 Rev A as sent to JLCPCB
    [Board connectors.SchDoc, Driver.SchDoc, Grounded clock.PrjPcb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]
2018-11-23 Graphical assets for the enclosure
2018-11-23 Rev B
    [Board connectors.SchDoc, Driver.SchDoc, Grounded clock.PrjPcb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]
2018-11-23 Le sigh 10000 pF != 100 nF, Rev B
    [Board.PcbDoc, Power supply.SchDoc]
2018-11-23 Gerbers as submitted to JLCPCB rev B
2018-11-26 Add power source handling for rev B board
2018-12-02 Code style changes and device name change to "Leave Time Behind"
2018-12-08 Scope observations from rev B; adjusted component values to rev B.1 (no layout changes)
    [Board.PcbDoc, Grounded clock.PrjPcb, MCU.SchDoc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]
2019-01-02 Start the PWM at the beginning of the working section of the tube
2019-01-12 Update board with new compensator and emperically determined slope compensation
    [Board.PcbDoc, Power supply.SchDoc]
2019-02-11 Rename board directory
2019-02-11 Remove Arduino & misc pin defs for Sparkfun board
2019-02-12 Rename Altium project
    [Board.PcbDoc, Leave Time Behind.PrjPcb]
2019-02-22 Update input filter script
2019-02-24 CAD files from Fusion 360
    [Back panel.stl, Enclosure.f3z, Frame.stl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]
2019-02-24 Re-org directories
    [Board connectors.SchDoc, Board.PcbDoc, Driver.SchDoc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]
2019-05-07 Add schematic PDF
2019-05-08 Add PCB photo

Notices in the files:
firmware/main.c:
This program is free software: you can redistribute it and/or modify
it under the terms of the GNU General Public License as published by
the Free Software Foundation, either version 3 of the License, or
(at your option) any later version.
